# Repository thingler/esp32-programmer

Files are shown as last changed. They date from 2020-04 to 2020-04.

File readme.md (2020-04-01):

# Thingler ESP32 Programmer

Thingler ESP32 Programmer is a USB Type-C to UART ESP32 programmer. The programmer is based on the CP2102N chip with two tactile buttons, BOOT and EN. The programmer can also be used to power the ESP32 (3.3V) chip and read log data sent from the ESP32 chip.

Thingler ESP32 Programmer has been designed for the [Thingler ESP32-PICO-D4 Module](https://github.com/thingler/esp32-pico-d4-module) but can be used to program any ESP32 chip.

Thingler ESP32 Programmer schematics and PCB has been designed with KiCad.

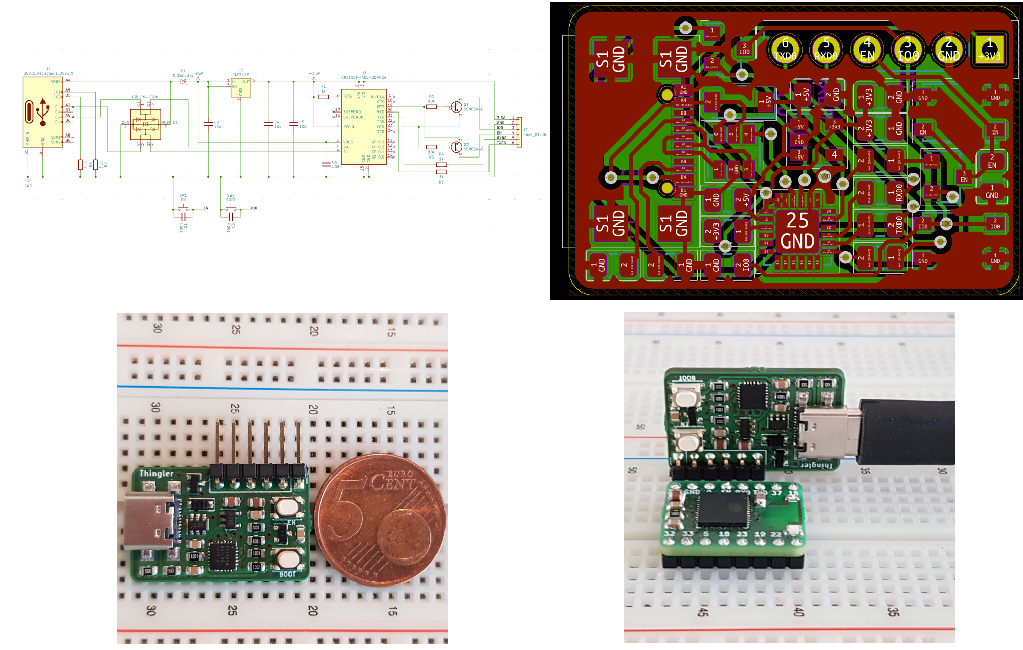
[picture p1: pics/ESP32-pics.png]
ESP32 Programmer


## Getting started

### Requirements

* Follow Espressif Systems [Getting started](https://docs.espressif.com/projects/esp-idf/en/latest/esp32/get-started/) instructions

* [Silicon Labs drivers](https://www.silabs.com/products/development-tools/software/usb-to-uart-bridge-vcp-drivers) in case the programmer is not recognized by the computer

* [KiCad](https://kicad-pcb.org/download/) for the schematics

### Build

The PCB wihout components can be ordered from [Aisler](https://aisler.net/p/ZDSBSTHE) or the PCB can be ordered from any fabrication houses by providing the [gerber files](Gerbers).

The following components has been used for the programmer:

| Ref | Qty | Manufacturer Part Number | Manufacturer | Description | Product Link |
| --- | --- | --- | --- | --- | --- |
| J1 | 1 | USB4110-GF-A | GCT | CONN USB 2.0 TYPE-C R/A SMT | [Digi-Key](https://www.digikey.fi/product-detail/en/gct/USB4110-GF-A/2073-USB4110-GF-A-1-ND/10384548) |
| J2 | 1 | 61300611021 | Wurth Elektronik | Headers & Wire Housings WR-PHD 2.54mm Hdr 6P Single RA Gold | [Mouser](https://www.mouser.fi/ProductDetail/Wurth-Elektronik/61300611021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) |
| U1 | 1 | USBLC6-2SC6 | STMicroelectronics | ESD Protection Low Cap | [Mouser](https://www.mouser.fi/ProductDetail/STMicroelectronics/USBLC6-2SC6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) |
| U2 | 1 | TLV75733PDBVR | Texas Instruments | LDO Voltage Regulators 1-A | [Mouser](https://www.mouser.fi/ProductDetail/Texas-Instruments/TLV75733PDBVR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) |
| U3 | 1 | CP2102N-A02-GQFN24 | Silicon Labs | USB Interface IC USB to UART bridge | [Mouser](https://www.mouser.fi/ProductDetail/Silicon-Labs/CP2102N-A02-GQFN24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) |
| SW1, SW2 | 2 | PTS815 SJK 250 SMTR LFS | C&K | Tactile Switch | [Digi-Key](https://www.digikey.fi/product-detail/en/c-k/PTS815-SJK-250-SMTR-LFS/CKN12216-1-ND/9947850) |
| Q1, Q2 | 2 | SS8050-G | Comchip Technology | Bipolar NPN Transistors | [Mouser](https://www.mouser.fi/ProductDetail/Comchip-Technology/SS8050-G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) |
| D1 | 1 | RB161MM-20TR | ROHM Semiconductor | Schottky Diode | [Mouser](https://www.mouser.fi/ProductDetail/ROHM-Semiconductor/RB161MM-20TR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) |
| R1, R4, R5 | 3 | RC0805FR-071KL | Yageo | 1 k ohm 1% 1/8W 0805 | [Digi-Key](https://www.digikey.fi/product-detail/en/yageo/RC0805FR-071KL/311-1.00KCRCT-ND/730391) |
| R2, R3 | 2 | CRCW080510K0FKEAC | Vishay / Dale | 10 k ohm 1% 1/8W 0805 | [Mouser](https://www.mouser.fi/ProductDetail/Vishay-Dale/CRCW080510K0FKEAC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) |
| R6, R7 | 2 | CRG0805F5K1 | TE Connectivity Passive Product | 5.1 k ohm 1% 1/8W 0805 | [Digi-Key](https://www.digikey.fi/product-detail/en/te-connectivity-passive-product/CRG0805F5K1/A126379CT-ND/7603434) |
| C1, C3, C5, C6 | 4 | 885012207098 | Wurth Elektronik | 100 nF 10% 0805 50V | [Mouser](https://www.mouser.fi/ProductDetail/Wurth-Elektronik/885012207098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) |
| C2, C4 | 2 | CGA4J1X7R0J106K125AC | TDK | 10 uF 10% 0805 6.3V | [Mouser](https://www.mouser.fi/ProductDetail/TDK/CGA4J1X7R0J106K125AC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) |

## License

Released under [GNU/GPL Version 3](LICENSE)

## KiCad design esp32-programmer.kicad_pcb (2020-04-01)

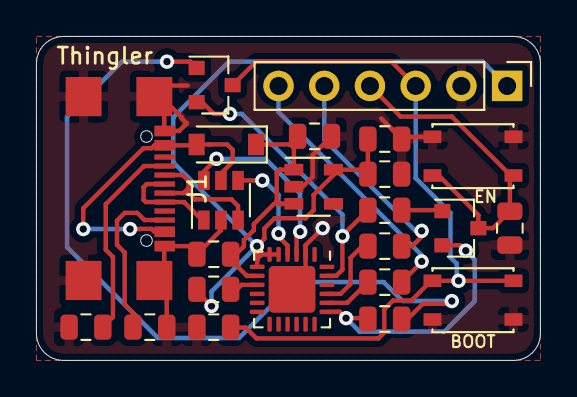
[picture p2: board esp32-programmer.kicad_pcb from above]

Board: 2 copper layers, 28.0 x 18.0 mm, 23 parts (0 on the bottom side), 21 nets.

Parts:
C1, C3, C5, C6: 100n; C_0805_2012Metric
C2, C4: 10u; C_0805_2012Metric
D1: D_Schottky; D_SOD-123
J1: USB_C_Receptacle_USB2.0; USB C
J2: Conn_01x06; PinHeader_1x06_P2.54mm_Vertical
Q1, Q2: SS8050-G; SOT-23
R1, R4, R5: 1k; R_0805_2012Metric
R2, R3: 10k; R_0805_2012Metric
R6, R7: 5.1k; R_0805_2012Metric
SW1: EN; PTS 815
SW2: BOOT; PTS 815
U1: USBLC6-2SC6; SOT-23-6
U2: TLV757P; SOT-23-5
U3: CP2102N-A01-GQFN24; QFN-24-1EP_4x4mm_P0.5mm_EP2.6x2.6mm

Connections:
+3V3: C4.1, C5.2, J2.1, R1.2, U2.5, U3.5, U3.6, U3.7
+5V: C2.1, C6.2, D1.1, U2.1, U2.3, U3.8
/EN: C1.2, J2.4, Q2.3, SW1.2
/IO0: C3.2, J2.3, Q1.3, SW2.2
/RXD0: J2.5, R4.1
/TXD0: J2.6, R5.2
GND: C1.1, C2.2, C3.1, C4.2, C5.1, C6.1, J1.A1, J1.B1, J1.S1, J2.2, R6.1, R7.1, SW1.1, SW2.1, U1.2, U2.2, U3.2, U3.25
unnamed: D1.2, J1.A4, J1.B4, U1.5
unnamed: J1.A5, R7.2
unnamed: J1.A6, J1.B6, U1.1
unnamed: J1.A7, J1.B7, U1.3
unnamed: J1.B5, R6.2
unnamed: Q1.1, R2.1
unnamed: Q1.2, R3.2, U3.23
unnamed: Q2.1, R3.1
unnamed: Q2.2, R2.2, U3.19
unnamed: R1.1, U3.9
unnamed: R4.2, U3.21
unnamed: R5.1, U3.20
unnamed: U1.4, U3.4
unnamed: U1.6, U3.3

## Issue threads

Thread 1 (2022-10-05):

TLV75733 IC: burn down after plug into PC

skyfall133, 2022-10-05:
I used your PCBs file for making real board. After assembling all the components following your list, the board could connect to PC(Showed port on the Device Manager-Win10). However, after few seconds, the TLV75733 IC burn down. Could anyone suggest me the solution?
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

jarl-tornroos, 2022-10-05:
Sad to hear that!

Was there anything else connected to the 3.3V output of the programmer? The IC should be able to handle 1A and there is some type of current limiter. Are you able to measure the input voltage to the IC? It should be 5V and the resistors R6 and R7 are there to communicate to the USB PD to deliver 5V.

skyfall133, 2022-10-06:
> Sad to hear that!
>
> Was there anything else connected to the 3.3V output of the programmer? The IC should be able to handle 1A and there is some type of current limiter. Are you able to measure the input voltage to the IC? It should be 5V and the resistors R6 and R7 are there to communicate to the USB PD to deliver 5V.

The 3.3V output was not connect to any board or IC. I just plugged it to PC to test voltage by the VOM, first. The input voltage to TLV75733 IC is about 5V.

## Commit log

2020-03-30 initial commit :tada:
    [esp32-programmer-B_Cu.gbr, esp32-programmer-B_Mask.gbr, esp32-programmer-B_Paste.gbr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]
2020-04-01 Adding README.md
    [esp32-programmer-B_Cu.gbr, esp32-programmer-B_Mask.gbr, esp32-programmer-B_Paste.gbr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]
